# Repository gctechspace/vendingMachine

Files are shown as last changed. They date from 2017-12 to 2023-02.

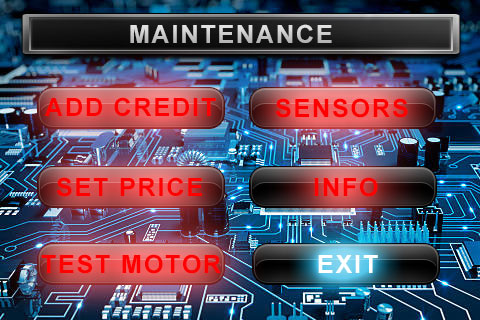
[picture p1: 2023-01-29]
NextionDisplay/maintenanceP.jpg

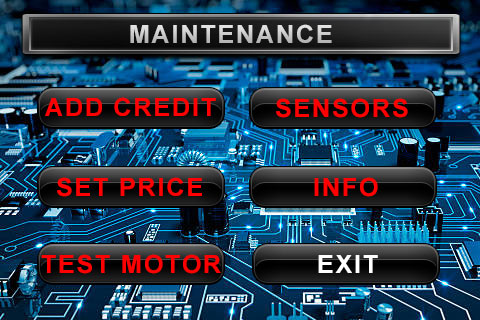
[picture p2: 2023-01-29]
NextionDisplay/maintenance.jpg

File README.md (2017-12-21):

# vendingMachine

**************************Version 2******12/17***************
It's Been awhile ;-)
PCB needs a massive update!!! but will still work *enough*.
Moving to a Nextion 2.4" Touch Screen display and ditching the old Keypad.
Will probably move to an ESP32/8266 for Comms.
......More To Come

**************************Version 1******12/14***************
A Vending machine system using:
Atmega1284
Coin Selector <= Accepts 50c, $1 & $2
2.4" QVga tft <= Price & Info Display
SDCard	      <= Stock List & info
RFID Reader   <= For member discount & management functions
Breakouts for:
Bluetooth
NRF24L01 Radio's
ESP01 Wifi module
Intergrates with old keypad

Use's Shift registers to control despencing of Items.
Motors are multiplexed with Highside drivers and transistor arrays.
All Motor circuit have been changed to allow despence detection and allow
tray removal detection.

Project By...
SkipXtian
MickMorri
JamesSapsford
Spidie

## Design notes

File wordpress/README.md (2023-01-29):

# WordPress Vending Machine stuff

This folder contains version controlled stuff from the `wp-content/` folder in WordPress.

A description of contents are:

- `plugins/gcts-vending/` = this WordPress plugin lets us render some buttons on the page. The user can dispense products from their WooCommerce order using these buttons. It does the talking to MQTT.
- `themes/vend/` = this custom WordPress theme lets us delete a lot of the default WordPress UI and create a nice custom shop front end.
- `theme/vend/woocommerce/emails/customer-processing-order.php` = this is an "overwrite" for the default WooCommerce email that is sent our. We include a link to "dispense" items in this email.

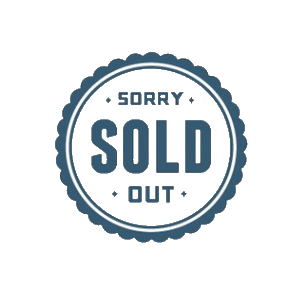
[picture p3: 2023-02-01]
wordpress/themes/vend/media/outOfStock.png

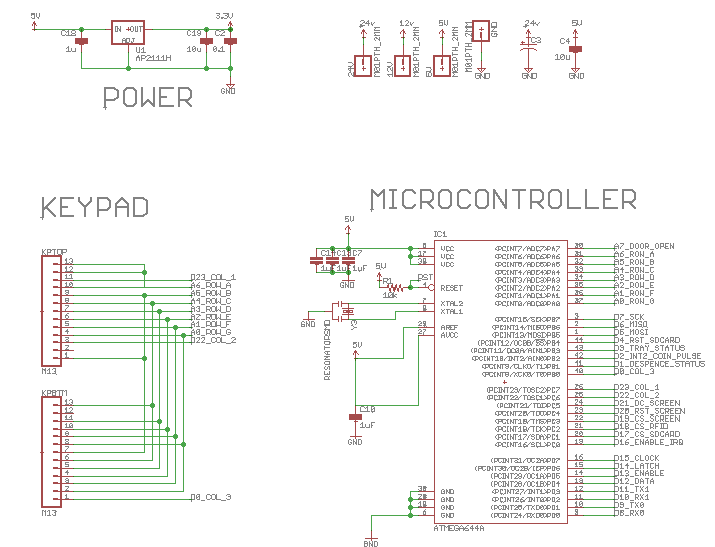
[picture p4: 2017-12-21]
PCB/PCB-uC.png

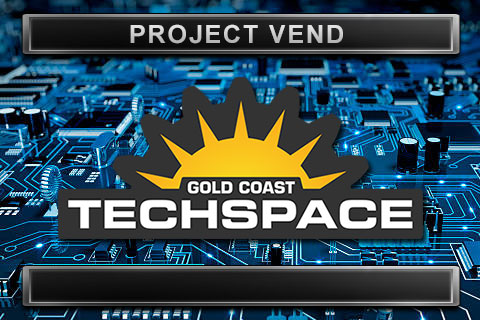
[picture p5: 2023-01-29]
NextionDisplay/start.jpg

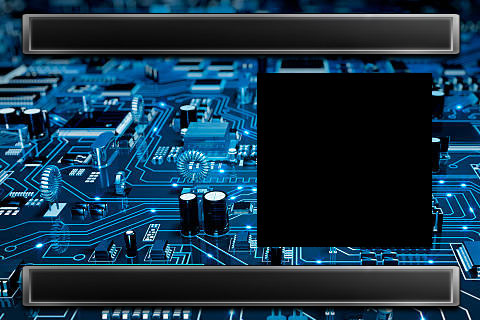
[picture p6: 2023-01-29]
NextionDisplay/info.jpg

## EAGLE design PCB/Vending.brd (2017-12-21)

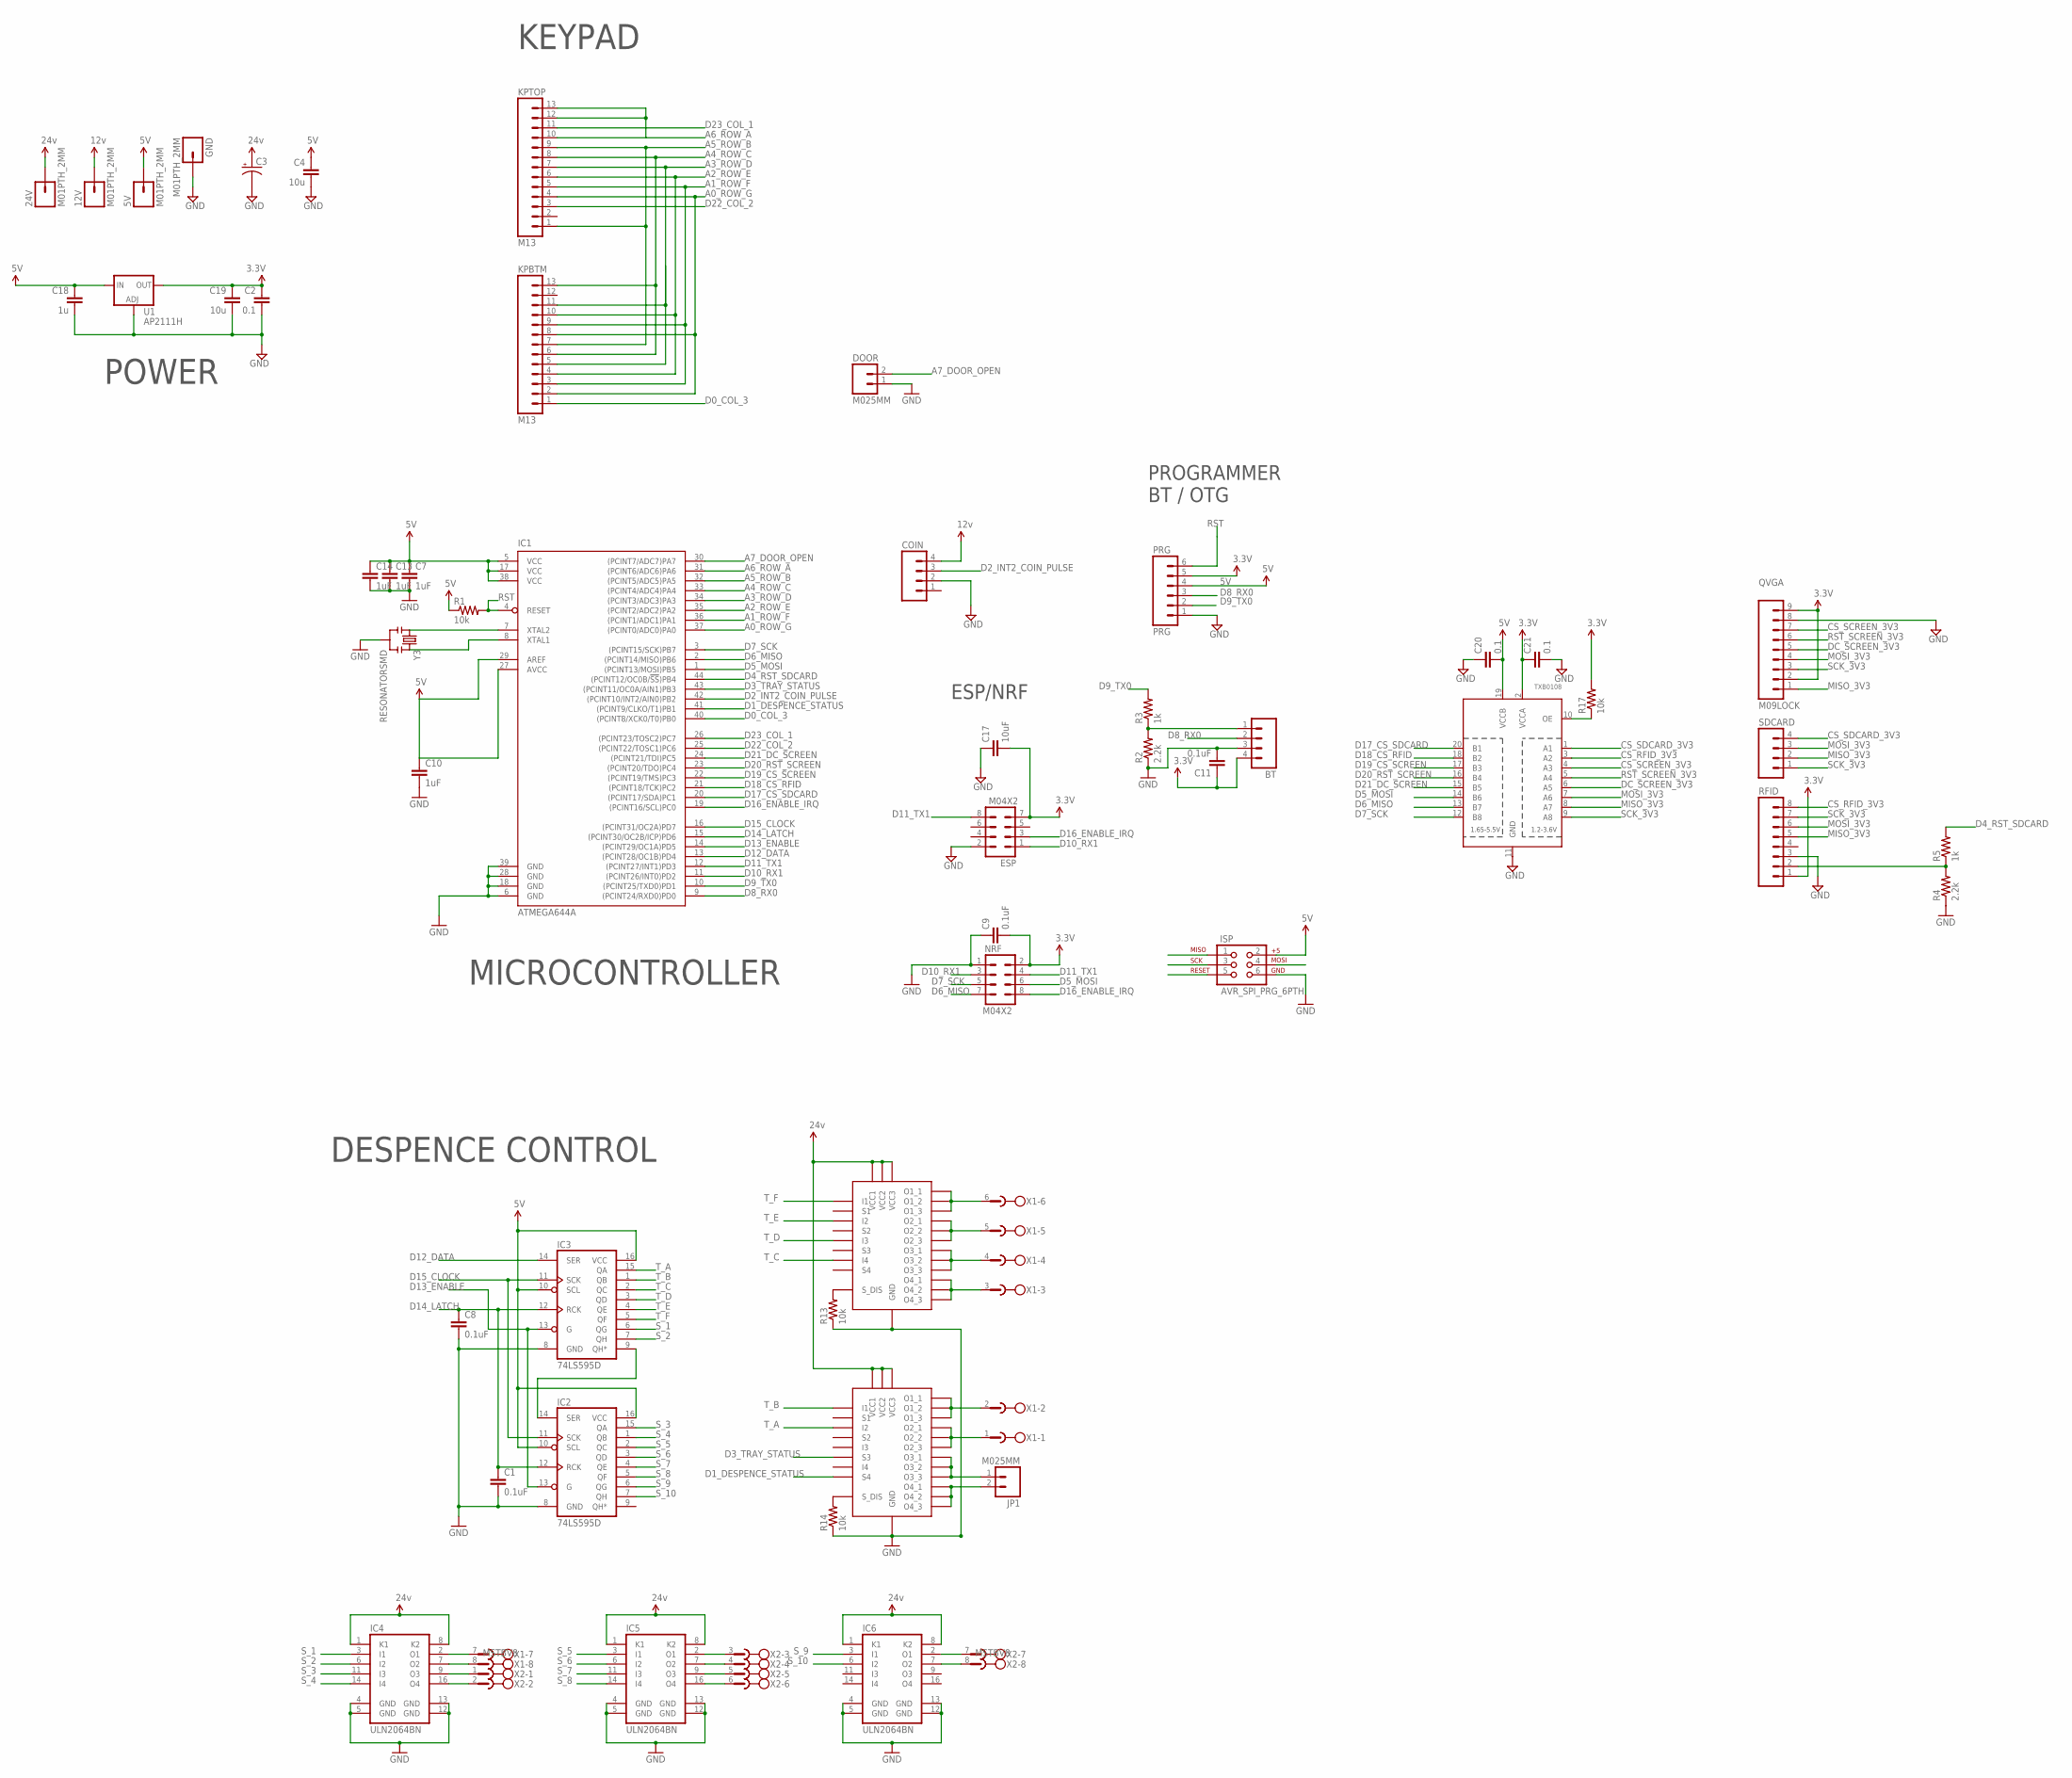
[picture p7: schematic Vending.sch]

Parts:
5V, 12V, 24V: M01PTH_2MM; 1X01_2MM
BT: M04PTH; 1X04
C1, C8, C9, C11: 0.1uF; 0805
C2, C20, C21: 0.1; 0805
C3: CAP_POLPTH4; CPOL-RADIAL-1000UF-25V
C4, C19: 10u; 0805-CAP
C7, C10, C13, C14: 1uF; 0805
C17: 10uF; 0805
C18: 1u; 0805
COIN: M04PTH; 1X04
DOOR: M025MM; SCREWTERMINAL-5MM-2
ESP: M04X2; 2X4
GND: M01PTH_2MM; 1X01_2MM
IC1: ATMEGA644A; TQFP44
IC2, IC3: 74LS595D; SO16
IC4, IC5, IC6: ULN2064BN; DIL16
ISP: AVR_SPI_PRG_6PTH; 2X3
JP1: M025MM; SCREWTERMINAL-5MM-2
KPBTM: M13; 1X13
KPTOP: M13; 1X13
NRF: M04X2; 2X4
PRG: PRG; 1X06
QVGA: M09LOCK; 1X09_LOCK
R1, R13, R14, R17: 10k; 0805
R2, R4: 2.2k; 0805
R3, R5: 1k; 0805
RFID: M08LOCK; 1X08_LOCK
SDCARD: M04LOCK; 1X04_LOCK
TXB0108: TXB0108PWR; TSSOP20
U1: AP2111H; SOT223
U$2, U$3: VNQ5E160K-E; POWERS0-24
X1: MSTBV8
X2: MSTBV8; MPN MSTBV 2,5/8-GF-5.08
Y3: RESONATORSMD; RESONATOR-SMD

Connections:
3.3V: BT.4, C2.1, C9.2, C11.1, C17.2, C19.1, C21.1, ESP.7, NRF.2, PRG.5, QVGA.2, QVGA.9, R17.2, RFID.1, TXB0108.2 (VCCA), U1.2 (OUT)
5V: 5V.1, C4.1, C7.1, C10.1, C13.1, C14.1, C18.1, C20.2, IC1.5 (VCC), IC1.17 (VCC), IC1.27 (AVCC), IC1.29 (AREF), IC1.38 (VCC), IC2.10 (SCL), IC2.16 (VCC), IC3.10 (SCL), IC3.16 (VCC), ISP.2, PRG.4, R1.1, TXB0108.19 (VCCB), U1.3 (IN)
12V: 12V.1, COIN.4
24V: 24V.1, C3.1 (+), IC4.1 (K1), IC4.8 (K2), IC5.1 (K1), IC5.8 (K2), IC6.1 (K1), IC6.8 (K2), U$2.1 (VCC1), U$2.12 (VCC2), U$2.VCC (VCC3), U$3.1 (VCC1), U$3.12 (VCC2), U$3.VCC (VCC3)
A0_ROW_G: IC1.37 ((PCINT0/ADC0)PA0), KPBTM.2, KPBTM.8, KPTOP.4
A1_ROW_F: IC1.36 ((PCINT1/ADC1)PA1), KPBTM.3, KPBTM.9, KPTOP.5
A2_ROW_E: IC1.35 ((PCINT2/ADC2)PA2), KPBTM.4, KPBTM.10, KPTOP.6
A3_ROW_D: IC1.34 ((PCINT3/ADC3)PA3), KPBTM.5, KPBTM.11, KPTOP.7
A4_ROW_C: IC1.33 ((PCINT4/ADC4)PA4), KPBTM.6, KPBTM.13, KPTOP.8
A5_ROW_B: IC1.32 ((PCINT5/ADC5)PA5), KPBTM.7, KPTOP.1, KPTOP.9
A6_ROW_A: IC1.31 ((PCINT6/ADC6)PA6), KPTOP.10, KPTOP.12, KPTOP.13
A7_DOOR_OPEN: DOOR.2, IC1.30 ((PCINT7/ADC7)PA7)
CS_RFID_3V3: RFID.8, TXB0108.3 (A2)
CS_SCREEN_3V3: QVGA.7, TXB0108.4 (A3)
CS_SDCARD_3V3: SDCARD.4, TXB0108.1 (A1)
D0_COL_3: IC1.40 ((PCINT8/XCK0/T0)PB0), KPBTM.1
D1_DESPENCE_STATUS: IC1.41 ((PCINT9/CLKO/T1)PB1), U$3.10 (S4)
D2_INT2_COIN_PULSE: COIN.3, IC1.42 ((PCINT10/INT2/AIN0)PB2)
D3_TRAY_STATUS: IC1.43 ((PCINT11/OC0A/AIN1)PB3), U$3.8 (S3)
D4_RST_SDCARD: IC1.44 ((PCINT12/OC0B/!SS!)PB4), R5.2
D5_MOSI: IC1.1 ((PCINT13/MOSI)PB5), ISP.4, NRF.6, TXB0108.14 (B6)
D6_MISO: IC1.2 ((PCINT14/MISO)PB6), ISP.1, NRF.7, TXB0108.13 (B7)
D7_SCK: IC1.3 ((PCINT15/SCK)PB7), ISP.3, NRF.5, TXB0108.12 (B8)
D8_RX0: BT.2, IC1.9 ((PCINT24/RXD0)PD0), PRG.3
D9_TX0: IC1.10 ((PCINT25/TXD0)PD1), PRG.2, R3.2
D10_RX1: ESP.1, IC1.11 ((PCINT26/INT0)PD2), NRF.3
D11_TX1: ESP.8, IC1.12 ((PCINT27/INT1)PD3), NRF.4
D12_DATA: IC1.13 ((PCINT28/OC1B)PD4), IC3.14 (SER)
D13_ENABLE: IC1.14 ((PCINT29/OC1A)PD5), IC2.13 (G), IC3.13 (G)
D14_LATCH: C1.1, C8.1, IC1.15 ((PCINT30/OC2B/ICP)PD6), IC2.12 (RCK), IC3.12 (RCK)
D15_CLOCK: IC1.16 ((PCINT31/OC2A)PD7), IC2.11 (SCK), IC3.11 (SCK)
D16_ENABLE_IRQ: ESP.3, IC1.19 ((PCINT16/SCL)PC0), NRF.8
D17_CS_SDCARD: IC1.20 ((PCINT17/SDA)PC1), TXB0108.20 (B1)
D18_CS_RFID: IC1.21 ((PCINT18/TCK)PC2), TXB0108.18 (B2)
D19_CS_SCREEN: IC1.22 ((PCINT19/TMS)PC3), TXB0108.17 (B3)
D20_RST_SCREEN: IC1.23 ((PCINT20/TDO)PC4), TXB0108.16 (B4)
D21_DC_SCREEN: IC1.24 ((PCINT21/TDI)PC5), TXB0108.15 (B5)
D22_COL_2: IC1.25 ((PCINT22/TOSC1)PC6), KPTOP.3
D23_COL_1: IC1.26 ((PCINT23/TOSC2)PC7), KPTOP.11
DC_SCREEN_3V3: QVGA.5, TXB0108.6 (A5)
GND: BT.3, C1.2, C2.2, C3.2 (-), C4.2, C7.2, C8.2, C9.1, C10.2, C11.2, C13.2, C14.2, C17.1, C18.2, C19.2, C20.1, C21.2, COIN.2, DOOR.1, ESP.2, GND.1, IC1.6 (GND), IC1.18 (GND), IC1.28 (GND), IC1.39 (GND), IC2.8 (GND), IC3.8 (GND), IC4.4 (GND), IC4.5 (GND), IC4.12 (GND), IC4.13 (GND), IC5.4 (GND), IC5.5 (GND), IC5.12 (GND), IC5.13 (GND), IC6.4 (GND), IC6.5 (GND), IC6.12 (GND), IC6.13 (GND), ISP.6, NRF.1, PRG.1, QVGA.8, R2.1, R4.1, R13.1, R14.1, RFID.3, TXB0108.11 (GND), U1.1 (ADJ), U$2.2 (GND), U$3.2 (GND), Y3.2
MISO_3V3: QVGA.1, RFID.5, SDCARD.2, TXB0108.8 (A7)
MOSI_3V3: QVGA.4, RFID.6, SDCARD.3, TXB0108.7 (A6)
unnamed: IC2.14 (SER), IC3.9 (QH*)
unnamed: IC1.7 (XTAL2), Y3.1
unnamed: IC1.8 (XTAL1), Y3.3
unnamed: IC4.9 (O3), X2.1
unnamed: IC4.2 (O1), X1.7
unnamed: BT.1, R2.2, R3.1
unnamed: IC4.7 (O2), X1.8
unnamed: IC4.16 (O4), X2.2
unnamed: IC5.2 (O1), X2.3
unnamed: IC5.7 (O2), X2.4
unnamed: IC6.2 (O1), X2.7
unnamed: IC6.7 (O2), X2.8
unnamed: R13.2, U$2.11 (S_DIS)
unnamed: R14.2, U$3.11 (S_DIS)
unnamed: R4.2, R5.1, RFID.2
unnamed: U$3.22 (O1_3), U$3.23 (O1_2), U$3.24 (O1_1), X1.2
unnamed: U$3.19 (O2_3), U$3.20 (O2_2), U$3.21 (O2_1), X1.1
unnamed: IC5.9 (O3), X2.5
unnamed: IC5.16 (O4), X2.6
unnamed: R17.1, TXB0108.10 (OE)
P1: U$2.22 (O1_3), U$2.23 (O1_2), U$2.24 (O1_1), X1.6
P2: U$2.19 (O2_3), U$2.20 (O2_2), U$2.21 (O2_1), X1.5
P3: U$2.16 (O3_3), U$2.17 (O3_2), U$2.18 (O3_1), X1.4
P4: U$2.13 (O4_3), U$2.14 (O4_2), U$2.15 (O4_1), X1.3
P7: JP1.1, U$3.16 (O3_3), U$3.17 (O3_2), U$3.18 (O3_1)
P8: JP1.2, U$3.13 (O4_3), U$3.14 (O4_2), U$3.15 (O4_1)
RST: IC1.4 (RESET), ISP.5, PRG.6, R1.2
RST_SCREEN_3V3: QVGA.6, TXB0108.5 (A4)
SCK_3V3: QVGA.3, RFID.7, SDCARD.1, TXB0108.9 (A8)
S_1: IC3.6 (QG), IC4.3 (I1)
S_2: IC3.7 (QH), IC4.6 (I2)
S_3: IC2.15 (QA), IC4.11 (I3)
S_4: IC2.1 (QB), IC4.14 (I4)
S_5: IC2.2 (QC), IC5.3 (I1)
S_6: IC2.3 (QD), IC5.6 (I2)
S_7: IC2.4 (QE), IC5.11 (I3)
S_8: IC2.5 (QF), IC5.14 (I4)
S_9: IC2.6 (QG), IC6.3 (I1)
S_10: IC2.7 (QH), IC6.6 (I2)
T_A: IC3.15 (QA), U$3.5 (I2)
T_B: IC3.1 (QB), U$3.3 (I1)
T_C: IC3.2 (QC), U$2.9 (I4)
T_D: IC3.3 (QD), U$2.7 (I3)
T_E: IC3.4 (QE), U$2.5 (I2)
T_F: IC3.5 (QF), U$2.3 (I1)

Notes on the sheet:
DESPENCE CONTROL
KEYPAD
MICROCONTROLLER
POWER
ESP/NRF
PROGRAMMER BT / OTG

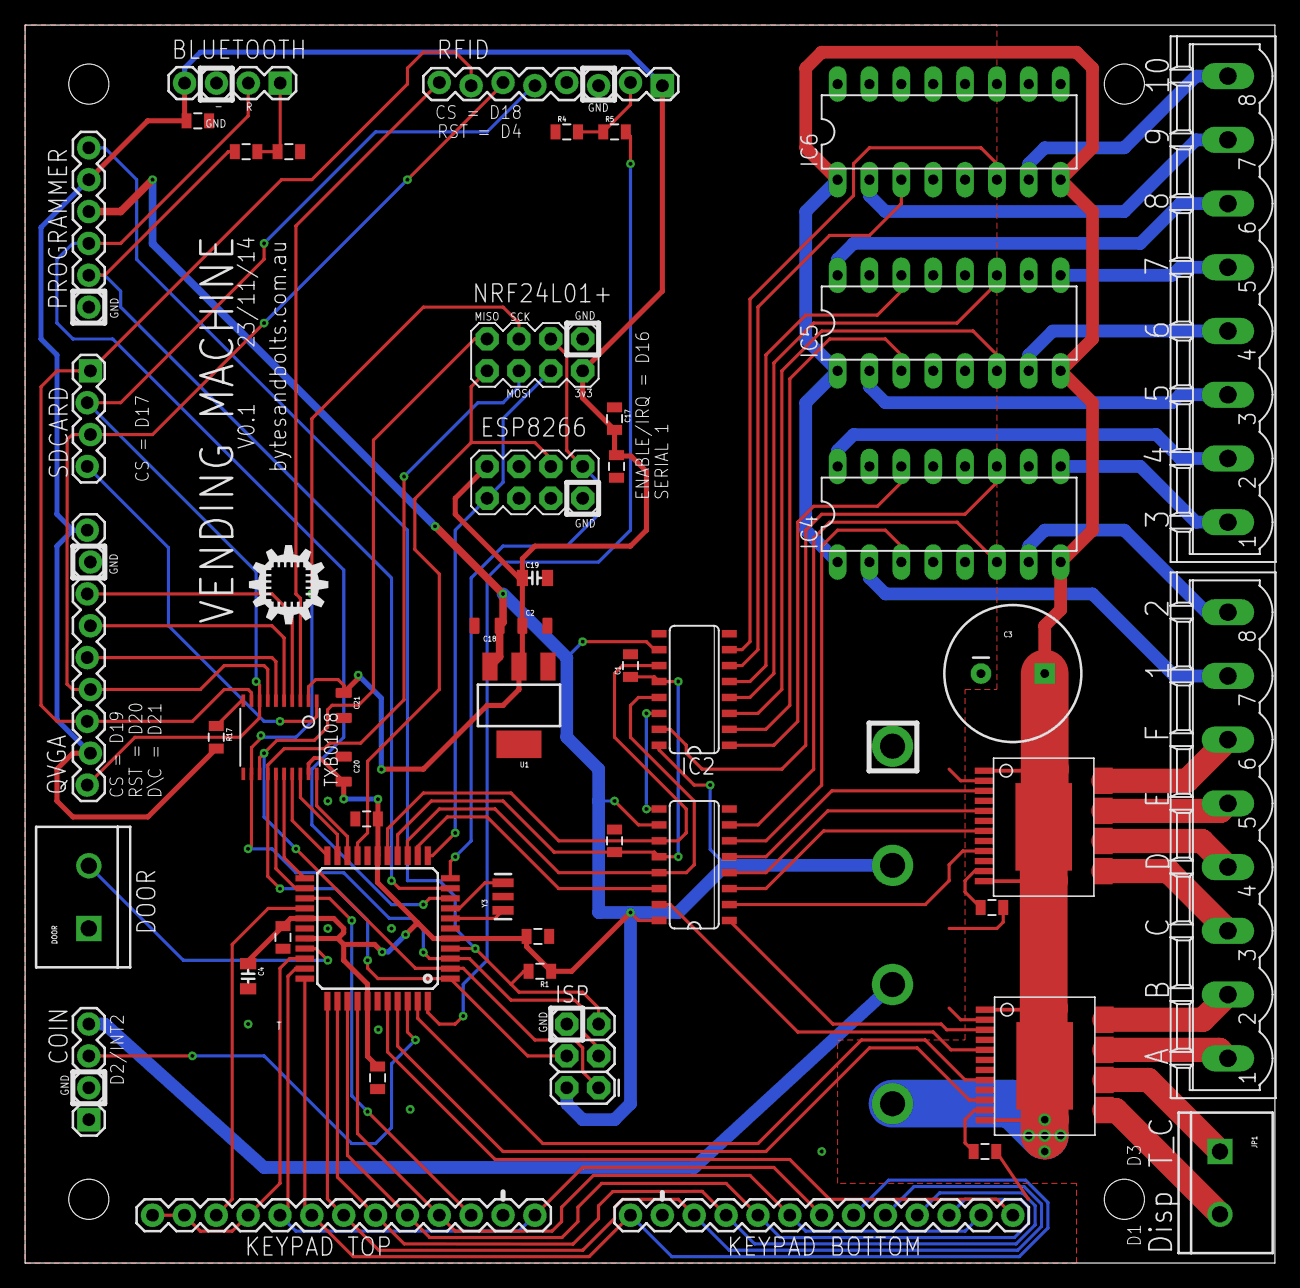
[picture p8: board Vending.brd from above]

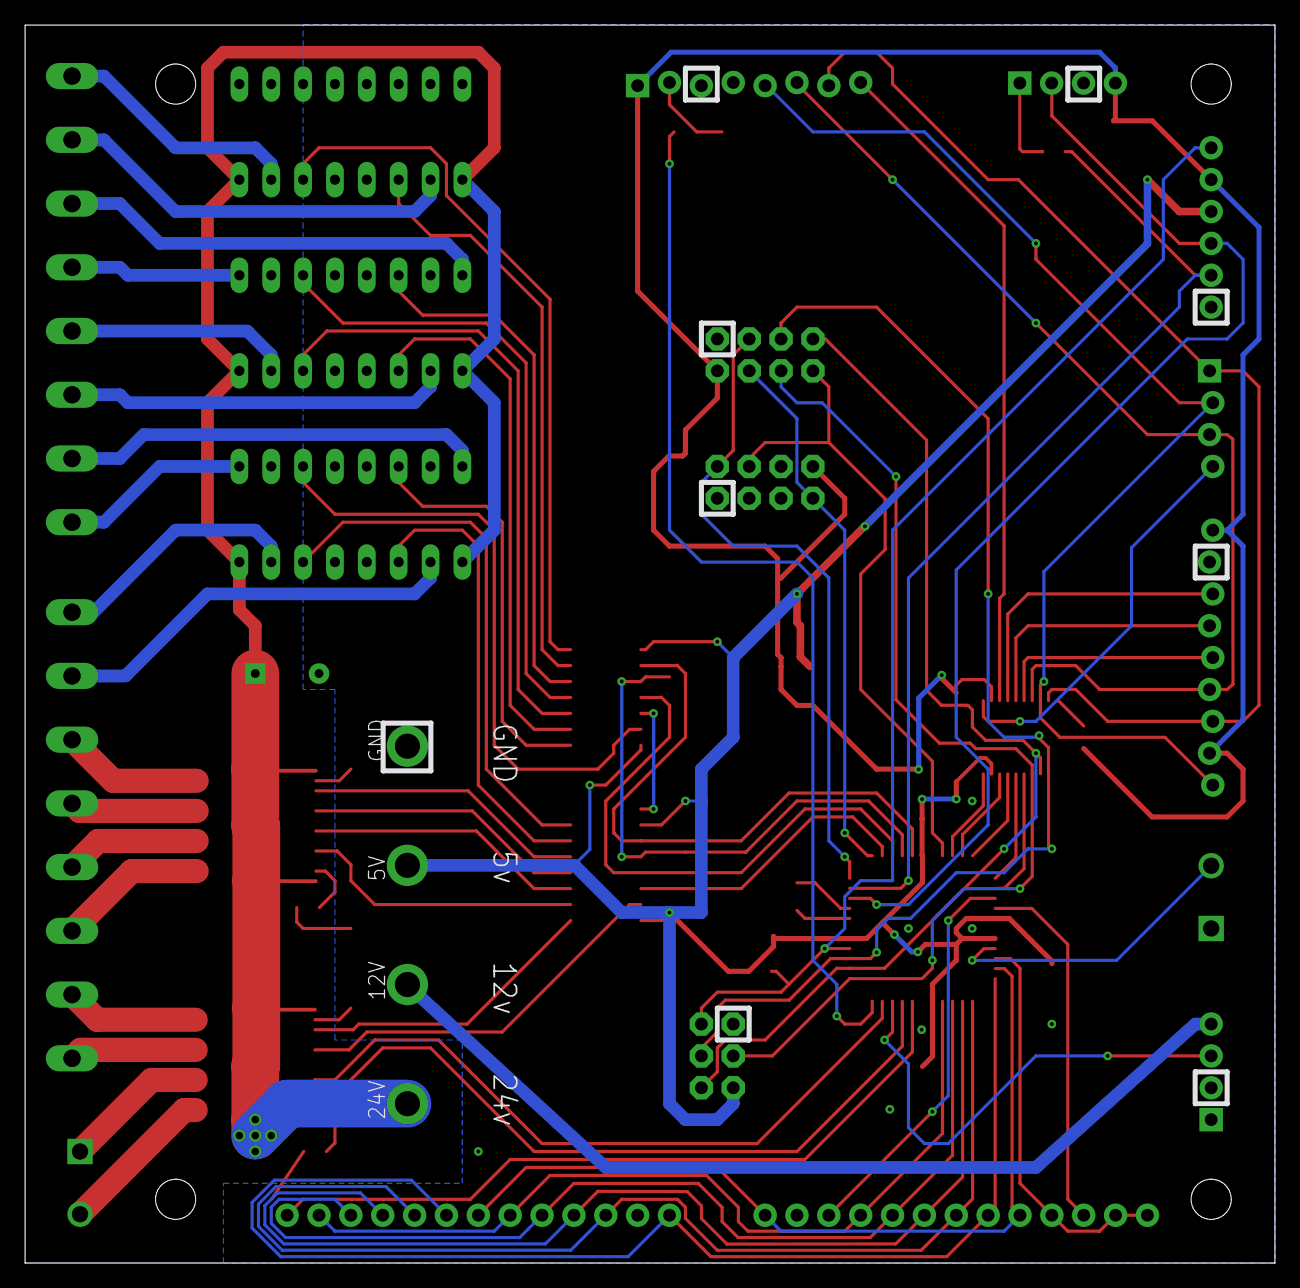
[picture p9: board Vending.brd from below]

Board: 2 copper layers, 99.6 x 98.7 mm, 55 parts (4 on the bottom side), 88 nets.

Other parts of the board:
U$1: ID_LOGO_X0.25

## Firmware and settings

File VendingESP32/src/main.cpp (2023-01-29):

#include <Arduino.h>

#include "SPI.h"
#include "MFRC522.h"

#include "WiFi.h"
// #include <ESPmDNS.h>
#include <WiFiUdp.h>
#include <NTPClient.h>
#include <ArduinoOTA.h>
extern "C"
{
#include "freertos/FreeRTOS.h"
#include "freertos/timers.h"
}
#include <AsyncMqttClient.h>
#include <HardwareSerial.h>
#include "credentials.h"
#include "FS.h"
#include "SPIFFS.h" //A way to store configuration with some memory protection

//****************** FUNCTION PROTOTYPES ******************
void initOTA(void);
void write2Nextion(String targetField, String value);
void write2Nextion(String targetField, unsigned long value);
byte getItemIndex(char row, char column);

// HardwareSerial dispenceSerial(1); // Pins 16,17
HardwareSerial dispenceSerial(2); // Pins 4,15

bool attemptDispence = false;
unsigned long attemptDispenceTime;
bool maintance = false; //won't publish to broker a dispence if in maintaince mode (does not effect stock count)

#define COIN_PULSE_PIN 27 //Right on the end of the serial connection to the Nextion
#define NO_ITEM_SELECTED '\0'
// byte itemArrayIndex = 0;

#define ITEM_COUNT 39

typedef struct
{
	// char fileName[3];  //itemArrayIndex in a char array
	char itemName[15];
	uint16_t price; //Divide by 100 ie 350 = 3.5
	byte stockLeft;
	// byte stockReserved;
	char description[25];
} stockStruct;

stockStruct item[ITEM_COUNT];

typedef struct
{
	char itemRow;
	char itemColumn;
	uint16_t price;
	// unsigned long timeSelected;
} itemStruct;

itemStruct selectedItem;

//item[itemArrayIndex].name = "Test";

#define DOOR_OPEN_PIN 14 //WS2812 Pinout

//****************** CONNECTION HANDLING ******************
WiFiClient espClient;
AsyncMqttClient mqttClient;
TimerHandle_t mqttReconnectTimer;
TimerHandle_t wifiReconnectTimer;

//****************** TIME HANDLING ******************
WiFiUDP ntpUDP;
// You can specify the time server pool and the offset (in seconds, can be
// changed later with setTimeOffset() ). Additionaly you can specify the
// update interval (in milliseconds, can be changed using setUpdateInterval() ).
#define TIMEZONE 10 //Australia Brisbane GMT+10
NTPClient timeClient(ntpUDP, "au.pool.ntp.org", 3600 * TIMEZONE, 60000);

//**********************Coin Mech**********************
volatile unsigned int coinCredit = 0; //Holds the current inserted coins credit
volatile unsigned long coinInsertedTime = 0;
unsigned int moneyInserted = 0;
#define coinPulseDelay 150

void coinInsertedISR()
{
	//The function that is called every time it receives a pulse
	static unsigned long lastPulse = 0;
	if (millis() - lastPulse > 80)
	{
		lastPulse = millis();
		coinInsertedTime = lastPulse;
		coinCredit++;
	}
} //The coin selector is set to pulse once for every 50cents

//****************** CODE SEPERATION ******************
#include "fileSystem.esp"
#include "nextion.esp"
#include "connection.esp"
#include "rfid.esp"

/******************** Gives the pulses from the coin mech a value ******************/
void handleCoins()
{
	if (coinCredit != 0 && millis() - coinInsertedTime > coinPulseDelay)
	{
		// Serial.println(coinCredit);
		// Serial.println(moneyInserted);
		moneyInserted += coinCredit * 50;
		Serial.println(moneyInserted);
		Serial.println();
		coinCredit = 0;
		writePrice2Nextion("home.creditText.txt=", moneyInserted);
		char moneystr[6];
		itoa(moneyInserted, moneystr, 10);
		mqttClient.publish(MONEY_TOPIC, 1, 0, moneystr);
	}
}

void handleSelectedItem()
{
	if (selectedItem.itemRow != NO_ITEM_SELECTED && attemptDispence == false)
	{
		if (moneyInserted >= selectedItem.price)
		{
			logEvent("[LOG]: Atempting Dispecnce");
			attemptDispence = true;
			attemptDispenceTime = millis();
			dispenceSerial.print('<');
			dispenceSerial.print(selectedItem.itemRow);
			dispenceSerial.print(selectedItem.itemColumn);
			dispenceSerial.print(selectedItem.itemRow + selectedItem.itemColumn);
			dispenceSerial.print('>');
		}
	}
}

const byte numChars = 10;
char receivedChars[numChars];
boolean newData = false;
void recvWithStartEndMarkers()
{
	static boolean recvInProgress = false;
	static byte ndx = 0;
	char startMarker = '<';
	char endMarker = '>';
	char rc;
	unsigned long startTime = 0;

	while (dispenceSerial.available() > 0 && newData == false)
	{
		rc = dispenceSerial.read();

		if (recvInProgress == true)
		{
			if (rc != endMarker)
			{
				receivedChars[ndx] = rc;
				ndx++;
				if (ndx >= numChars)
				{
					ndx = numChars - 1;
				}
			}
			else
			{
				receivedChars[ndx] = '\0'; // terminate the string
				recvInProgress = false;
				// mqttClient.publish(DISPENCE_TOPIC, 0, 0, receivedChars);
				// numberOfMessages++;
				if (receivedChars[3] == '1') // SWAPPED 24/11/21
				{
					moneyInserted -= selectedItem.price;
					writePrice2Nextion("home.creditText.txt=", moneyInserted);
					item[getItemIndex(selectedItem.itemRow, selectedItem.itemColumn)].stockLeft -= 1;
					selectedItem.price = 0;
					selectedItem.itemRow = NO_ITEM_SELECTED;
				}
				else if (receivedChars[3] == '0') // SWAPPED 24/11/21
				{
					logEvent("[ERR]: Tray not found");
				}
				else if (receivedChars[3] == '2')
				{
					logEvent("[ERR]: Dispence Timeout");
				}
				else if (receivedChars[3] == '3')
				{
					logEvent("[ERR]: Bad Checksum");
				}
				mqttClient.publish(DISPENCE_TOPIC, 0, 0, receivedChars);
				attemptDispence = false;
				logEvent("[LOG]: End dispence");

				ndx = 0;
			}
		}
		else if (rc == startMarker)
		{
			recvInProgress = true;
			startTime = millis();
		}
	}
	if (recvInProgress == true && millis() - startTime > 3000)
	{
		recvInProgress = false;
		logEvent("[ERR]: Serial timeout");
	}
	if (attemptDispence == true && millis() - attemptDispenceTime > 15000)
	{
		attemptDispence = false;
		logEvent("[ERR]: Dispence Timed out");
		// writePrice2Nextion("home.creditText.txt=", "Error");
		char dispenced[5];
		dispenced[0] = selectedItem.itemRow;
		dispenced[1] = selectedItem.itemColumn;
		dispenced[2] = '|';
		dispenced[3] = '4';
		dispenced[4] = '\0';
		mqttClient.publish(DISPENCE_TOPIC, 1, 0, dispenced);
		selectedItem.price = 0;
		selectedItem.itemRow = NO_ITEM_SELECTED;
	}
}

void handleDispence()
{
	recvWithStartEndMarkers();
	// char dispenced[5];
	// if (dispenceSerial.available() > 0)
	// { //expecting "<A1|1>" row&column|sucess/failure
	// 	for (byte i = 0; i < 4; i++)
	// 	{
	// 		dispenced[i] = dispenceSerial.read();
	// 	}
	// 	if (maintance == false)
	// 	{
	// 		dispenced[4] = '\0';
	// 		if (dispenced[3] == '0')
	// 		{
	// 			moneyInserted -= selectedItem.price;
	// 			writePrice2Nextion("home.creditText.txt=", moneyInserted);
	// 			item[getItemIndex(selectedItem.itemRow, selectedItem.itemColumn)].stockLeft -= 1;
	// 			selectedItem.price = 0;
	// 			selectedItem.itemRow = NO_ITEM_SELECTED;
	// 		}
	// 		else if (dispenced[3] == '1')
	// 		{
	// 			logEvent("[ERR]: Tray not found");
	// 		}
	// 		else if (dispenced[3] == '2')
	// 		{
	// 			logEvent("[ERR]: Dispence Timeout");
	// 		}
	// 		else if (dispenced[3] == '3')
	// 		{
	// 			logEvent("[ERR]: Bad Checksum");
	// 		}
	// 		mqttClient.publish(DISPENCE_TOPIC, 1, 0, dispenced);
	// 		logEvent("[ERR]: What the?");
	// 	}
	// 	else
	// 	{
	// 		maintance = false;
	// 	}
	// 	attemptDispence = false;
	// 	logEvent("[ERR]: What the?");
	// }

	// if (attemptDispence == true && millis() - attemptDispenceTime > 15000)
	// {
	// 	attemptDispence = false;
	// 	logEvent("[ERR]: Dispence Timed out");
	// 	// writePrice2Nextion("home.creditText.txt=", "Error");
	// 	dispenced[0] = selectedItem.itemRow;
	// 	dispenced[1] = selectedItem.itemColumn;
	// 	dispenced[2] = '|';
	// 	dispenced[3] = '4';
	// 	dispenced[4] = '\0';
	// 	mqttClient.publish(DISPENCE_TOPIC, 1, 0, dispenced);
	// 	selectedItem.price = 0;
	// 	selectedItem.itemRow = NO_ITEM_SELECTED;
	// }
}

void doorStateChange()
{
	static boolean lastDoorState = digitalRead(DOOR_OPEN_PIN);
	boolean doorState = digitalRead(DOOR_OPEN_PIN);
	if (lastDoorState != doorState)
	{
		if (doorState == HIGH)
		{ //Door closed return to normal display
			logEvent("[INFO]: Door Closed");
			write2Nextion("page home");
		}
		else
		{ //Door opened show maintaince screen
			logEvent("[INFO]: Door Opened");
			write2Nextion("page maintance");
		}
		lastDoorState = doorState;
	}
}

//****** Returns the array index for an item location ******
byte getItemIndex(char row, char column)
{
	byte itemArrayIndex = 0;
	if (row == 'B')
		itemArrayIndex = 5;
	else if (row == 'C')
		itemArrayIndex = 10;
	else if (row == 'D')
		itemArrayIndex = 15;
	else if (row == 'E')
		itemArrayIndex = 25;
	else if (row == 'F')
		itemArrayIndex = 35;
	if (column == '0')
	{
		itemArrayIndex += column - 39;
	}
	else
	{
		itemArrayIndex += column - 49;
	}
	return itemArrayIndex;
}

//******************************* SETUP **********************************
void setup()
{

#ifndef DEBUG
	Serial.begin(115200);
	Serial.println("");
	Serial.println("Sketch init!");
	Serial.print("Compile Date / Time : ");
	Serial.print(__DATE__);
	Serial.print(" / ");
	Serial.println(__TIME__);
	Serial.println("");
#endif
	dispenceSerial.begin(9600, SERIAL_8N1, 25, 14); //4, 15);
													//nRF plug  x,x,Tx,GND
	// x,x,Rx,x

	//  Bolt GND,25,12    OLED GND,3v3,22,21
	// dispenceSerial.begin(9600, SERIAL_8N1, 16, 17);

	initNextion();

	initRFID();

	pinMode(DOOR_OPEN_PIN, INPUT_PULLUP);
	attachInterrupt(COIN_PULSE_PIN, coinInsertedISR, RISING); //If coinInt goes HIGH (a Pulse), call the coinInserted function
	pinMode(DOOR_OPEN_PIN, INPUT_PULLUP);
	// attachInterrupt(DOOR_OPEN_PIN, doorStateChangeISR, CHANGE);

	initWifi();
	initSpiffs();
	enableWDT(); //This is the core 1 watchdog timer, it's feed in houseKeeping.
}

//******************************* LOOP **********************************
void loop()
{
	houseKeeping(); //Wifi, MQTT etc

	doorStateChange(); //Enter Maintaince Mode
	handleNextion();   //Commands from touch screen
	handleCoins();
	handleSelectedItem();
	handleRFID();
	handleDispence();
}

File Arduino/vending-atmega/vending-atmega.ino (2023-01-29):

#define ver 002
/*
Possibilities:
Add ESP32/8266 and connect:
Coin Mech (through voltage divider)
Nextion Display (Serial)
VendingBoard (I2C)
*TFT* <= QR Codes or something similar

Leaving VendingBoard to Control Dispence
*/

#include "pinDef_v0_1.h"

volatile unsigned int coinCredit = 0;  //Holds the current inserted coins credit
volatile unsigned long coinInsertedTime = 0;
unsigned int moneyInserted = 0;
#define coinPulseDelay 150

//***************Libraries***********************

//RFID
#include <MFRC522.h>

//***************Instances**************************
MFRC522 mfrc522(RFID_CS, RFID_RST);



void setup()
{
  Serial.begin(115200);
  Serial1.begin(9600);
  Serial.print("Vending Machine, Version:");
  Serial.println(ver);
  Serial.println("Project by SkipXtian, DTBaker");

//  attachInterrupt(coinIn, coinInsertedISR, RISING);   //If coinInt goes HIGH (a Pulse), call the coinInserted function

  pinMode(despenceStatus, INPUT_PULLUP);
  pinMode(trayStatus, INPUT_PULLUP);

  //rfidInit();
  shiftRegInit();
}

void loop()
{
//  handleNextion();
  handleDispence();
  //detectTag();


//   if(coinCredit != 0 && millis()-coinInsertedTime>coinPulseDelay) {
//     Serial.println(coinCredit);
//     moneyInserted += coinCredit;
//     writeCredit2Nextion("home.creditText.txt=", moneyInserted);
//     coinCredit = 0;
//   }
}



void coinInsertedISR()
{
//The function that is called every time it receives a pulse
  coinInsertedTime = millis();
  coinCredit += 50;
}  //The coin selector is set to pulse once for every 50cents

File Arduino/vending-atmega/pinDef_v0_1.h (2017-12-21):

//Pin defines for Board Version 0.1  -  23/11/14

//PB0-7
#define KP_Col3        0
#define despenceStatus 1 //24v so INVERTED
#define coinIn         2
#define trayStatus     3 //24v so INVERTED
#define RFID_RST       4 //MUST BE OUTPUT
#define HW_MOSI        5
#define HW_MISO        6
#define HW_SCK         7

//PD0-7
#define HW_Rx          8
#define HW_Tx          9
#define ESP_Rx         10
#define ESP_Tx         11
#define Shift_DATA     12
#define Shift_ENABLE   13
#define Shift_LATCH    14
#define Shift_CLOCK    15

//PC0-7
#define ESP_ENABLE     16
#define SDCard_CS      17
#define RFID_CS        18
#define QVGA_CS        19
#define QVGA_RST       20
#define QVGA_DC        21
#define KP_Col2        22
#define KP_Col1        23

//PA0-7
#define KP_RowG        24//A0
#define KP_RowF        25//A1
#define KP_RowE        26//A2
#define KP_RowD        27//A3
#define KP_RowC        28//A4
#define KP_RowB        29//A5
#define KP_RowA        30//A6
#define doorStatus     31//A7

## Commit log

2017-12-21 Using an Old PCB design to get the vending machine working
    [Vending.brd, Vending.sch]
2023-02-01 Make email button really big

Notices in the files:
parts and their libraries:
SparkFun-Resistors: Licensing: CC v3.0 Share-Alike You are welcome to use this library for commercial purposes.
